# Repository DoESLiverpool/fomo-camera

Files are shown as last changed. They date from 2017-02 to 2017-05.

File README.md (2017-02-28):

# fomo-camera
An internet connected camera for live participatory photography

Fomo camera is an experiment to see what happens when you give a camera to an attendee at an event and then ask them to pass it on to the next person they bump into. The cameras will take images every minute and upload the result to the web.
The hardware will be contained in a large decorated enclosure.

In development for Light Night 17 at Maker Nights @ DoES

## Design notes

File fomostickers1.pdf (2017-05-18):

Fomocam.co.uk
See what we’ve been up to!

Fomocam.co.uk
where have we been?

Fomocam.co.uk
who have we met?
Fomocam.co.uk | Fomocam.co.uk | Fomocam.co.uk

Fomocam.co.uk
See what we’ve been up to!

Fomocam.co.uk
where have we been?

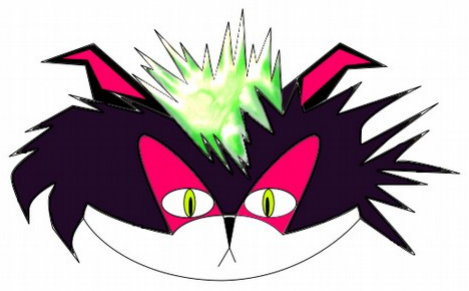
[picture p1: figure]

Fomocam.co.uk
who have we met?
Fomocam.co.uk | Fomocam.co.uk | Fomocam.co.uk

Fomocam.co.uk
See what we’ve been up to!

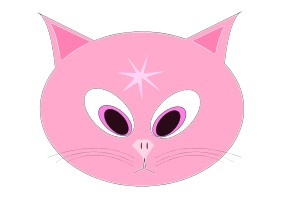
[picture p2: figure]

Fomocam.co.uk
where have we been?

Fomocam.co.uk
who have we met?
Fomocam.co.uk | Fomocam.co.uk | Fomocam.co.uk

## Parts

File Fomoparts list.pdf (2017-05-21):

Fomocam Parts list
Electronics
Raspberry Pi Zero (check it has camera conector so W or V 1.3) Raspbery Pi Camera module V2 or similar e.g. PiNoIR
Pi Zero Camera adaptor cable
NeoPixal strip (WS2812 5050 RGB LED)
8G SD Card
USB Modem Router 3G or 4G
5V powerbank (RS Pro PB-10400 10400mAh Power Bank Portable Charger) USB to MicroUSB B cable x 3
USB conector
3 x short lengths of electronics wire in different colours
Soldering iron & solder

Case
200 x 400mm sheet of 3mm Perspex* 4 x 50mm 2mm threaded bolts
8 x 2M nuts (best to have a few spare!) 2 x 20-25mm 2mm nylon bolts & nuts Hot glue gun & glue

Cover
EVA foam, felt, fur, googly eyes, sparkly things, what ever you want!
See coverings section for advice.
*You can get 3 boxes out of a 400 x 600mm sheet or play around with the layout to use 2 pieces smaller than 200 x 400mm

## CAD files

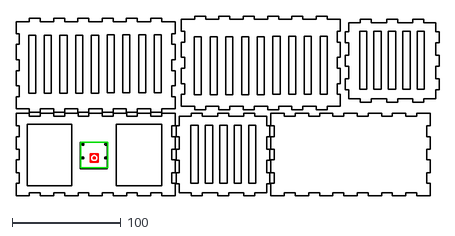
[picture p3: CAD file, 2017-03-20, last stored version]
fomoBox3.dxf
388.2 x 165.2

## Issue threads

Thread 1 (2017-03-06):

Design: Find the right balance of “it’s so cute!” and “it’s obviously a camera”

zarino, 2017-03-06:
I think you need something that:

* Looks like a camera (so it’s really obvious which direction to point it in)
* Looks like a creature with a face (so people look after it)
* Feels comfortable to hold (so people hold it)

Extra points if it lights up, or otherwise attracts attention to itself, so people notice it on the night.

None of these are quite right, but hopefully you can take bits from each (“this one looks a bit like a camera” … “this one is really cute” … “this one is furry”) as inspiration for FOMOcam.

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

/cc @huffeec @frabcus @awesomeliverpool

huffeec, 2017-03-06:
I've just been to chat with the sewing club, they were thinking of something like this. (Sort of similar to the top images..)

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

I really like the idea of building in a screen on the back with instructions too, makes it more interactive.

huffeec, 2017-03-11:
Talked with Dave about this at Maker day. He's looking at designs for the enclosure.
Will post updates here but keep the ideas coming, or speak to Dave..

drfraz, 2017-03-22:
Prototype foam body & perspex hard box for electronics made (see fomotest1.0 a & b in code section).
Initial consumer feedback seems positive for size & ease of throwing. Just need to cover it in fur....

drfraz, 2017-03-24:
Rough sketches for Liv & Mo
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

drfraz, 2017-04-08:
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

first fix

drfraz, 2017-04-08:
If we can't get hold of the sewing club then this might help!
http://laurenvenell.com/epic-how-to-make-a-3-d-plush-pattern-from-a-2-d-drawing/

drfraz, 2017-04-15:
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

drfraz, 2017-04-23:
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

Hope they are cute enough! Weight & fell seemed good with the camera in situ

Closed 2017-04-23.

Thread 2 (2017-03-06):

Investigate phone wifi hotspot as source of Internet connection

zarino, 2017-03-06:
If a mobile data board for the Raspberry Pi is proving expensive, could we instead assign each FOMOcam with a human "minder" who broadcasts a wifi hotspot for the FOMOcam to connect to?

Minders would need a phone, a sim card with sufficient data allowance and tethering enabled, and a spare USB battery pack, probably!!

huffeec, 2017-03-06:
Yes, I think this is the way to go. All we'd really lose, (and maybe not even) would be the accurate location data, which isn't really a problem.

drfraz, 2017-04-08:
Would a 3G modem dongle work OK? like one of these
 http://www.auto-gadget.com/index.php?route=product/product&product_id=58406&currency=GBP
looks a lot cheaper than the specific raspberry pi modems & people seem to be using them OK.
Only downside seems to be the aesthetics but we could remove the cover!

huffeec, 2017-04-23:
Have got and tested an o2 3g usb dongle.
Works on Raspbian and ran for 9 hours on the battery and uploaded images fine.
(I switched it off after nine hours to save data and because that's plenty long enough..)

Closed 2017-04-23.

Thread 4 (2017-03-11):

Check Pyinstagram as a route to upload media to Instagram

huffeec, 2017-03-11:
Look into this as an option to access the Instagram API via Python

https://github.com/eseom/pyinstagram

drfraz, 2017-04-08:
Here is a possible alternative
https://github.com/mgp25/Instagram-API

huffeec, 2017-04-23:
I didn't have much confidence in the Instagram API for this, so I'm currently using ftp to transfer images to a webserver.
[fomocam.co.uk](http://fomocam.co.uk) is running a basic bootstrap page that displays the most recent image and has paginated thumbs for older images. I'll add some social media buttons to encourage sharing and make it easy for us to post highlights to instagram/twitter accounts.

drfraz, 2017-04-23:
Yeah, if we are monitoring the site then we can ping off selected images every so often to the Instagram, twitter accounts, Police etc.

huffeec, 2017-05-05:
This is working now, and no police were needed at Festevol

Closed 2017-05-05.

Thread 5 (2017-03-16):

Name the cameras

huffeec, 2017-03-16:
Currently the cameras don't have particularly friendly names (fomocam1, fomocam2..)
Any suggestions for something a bit more engaging?

So far we've got FomoLiv and FomoMo....

SayBeano, 2017-03-16:
Maybe FomoViv or just Vivian, after Vivian Maier for one?

Her photos were found a few years back [by someone](http://www.johnmaloof.com/) who bought the contents of a storage container, Vivian was traced from a self portrait and later a documentary was made. That's about the most fitting suggestion I have.

The story could be further incorporated into an RFID / NFC / QRC that people inheriting the cameras can scan and be taken off to wikipedia. Mayber.

DoESsean, 2017-03-16:
FomoMoney and FomoProblems.

On Thu, Mar 16, 2017 at 10:05 AM, Mark Sabino <notifications@github.com>
wrote:

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

drfraz, 2017-03-24:
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

Closed 2017-04-23.

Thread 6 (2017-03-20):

Bluecoats meeting

drfraz, 2017-03-20:
Do you think we can meet with Bluecoats on Wednesday?
We need to see where we can project images & find out what they expect from us!
It could be a good place to try & get the 2 cameras to meet up rather than set them off from. Possibly start 1 at the Library & 1 at the Cathedral

huffeec, 2017-03-22:
Rob from Bluecoat is going to be around sometime today to talk about this. Do you want to chat with him? I've copied you into the email so you can pass on your phone number if you do.

drfraz, 2017-03-22:
Hi Chris, I'm at DoES so free to talk, my number is 07887 901668 but I can
pop across to Bluecoats easily
Fraz

On 22 Mar 2017 10:48 am, "huffeec" <notifications@github.com> wrote:

Rob from Bluecoat is going to be around sometime today to talk about this.
Do you want to chat with him? I've copied you into the email so you can
pass on your phone number if you do.

—
You are receiving this because you authored the thread.
Reply to this email directly, view it on GitHub
<https://github.com/DoESLiverpool/fomo-camera/issues/6#issuecomment-288362075>,
or mute the thread
<https://github.com/notifications/unsubscribe-auth/ASdoWVD2C0ogALmKEmOSaW4X1hoPgOUNks5roPyUgaJpZM4MjJBW>
.

huffeec, 2017-03-22:
Cool, Are you ok to chat with them?
Do you want me to pass on your number?

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

huffeec, 2017-03-22:
Chasing my tail a bit this week. But will definitely have a time lapse
ready camera for tomorrow. and I'll get onto the sewing club now.
Hope the exams went well?

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

drfraz, 2017-03-22:
Yes pass it on, just cutting the foam down to size. I will be down tomorrow
night so can catch up

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

huffeec, 2017-03-22:
So in the mean time Rob has called me.

He's offering one of the two TV's in the foyer, connected to a laptop, and
a small table somewhere.
Does that sound ok?

They need to agree it with Marie-Anne though.

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

drfraz, 2017-03-22:
That sounds great, I'll pop in in a bit and send a photo

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

drfraz, 2017-03-22:
I guess it is one of these screens that they mentioned. It would certainly
get a lot of notice. We could use my old laptop as it doesn't matter if it
gets nicked.
Also friendly sized foam.

On 22 Mar 2017 11:30 am, "David Frazer" <lazy.morepork@gmail.com> wrote:

That sounds great, I'll pop in in a bit and send a photo

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

Closed 2017-04-23.

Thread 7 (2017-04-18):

Testing times

drfraz, 2017-04-18:
Good news that we can test Fomocam at the Invisible wind Factory on 30th April!

drfraz, 2017-04-23:
I've opened this as a project. No idea if that's the right thing or not but I like the idea.

huffeec, 2017-04-23:
Why not..

drfraz, 2017-04-29:
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

drfraz, 2017-05-01:
Pretty successful test run here are some of the main issues

Instructions aren't obvious : try parcel tags with them on.
              Web address on one side & instructions on the other?

Kids these days have short attention spans: try photo every 30 seconds.
               Should have enough data & means only 20 seconds when the camera isn't doing something.

IR camera produces some very weird colours: try to make it a feature.
              If we use it in Vivian & say that he sees the world in a different way which can be both disturbing
               &/or beautiful. good for inclusivity of the differently abled, autistic,etc & philosophical; is any   
               world view the right one?

 Very positive feedback & interest from most people with several wanting to buy one

drfraz, 2017-05-01:
Also seems to be plenty of charge left after about 8 hours!

huffeec, 2017-05-05:
I also learned I'm going to need a backup battery for my own phone..

Closed 2017-05-06.

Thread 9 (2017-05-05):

Create instructions label

huffeec, 2017-05-05:
Make a label for the cameras that makes the instructions more obvious.
Include text from back of camera and web address.

Needs to be fairly durable so more than card. What fabrics etch well? Leather?

drfraz, 2017-05-05:
Might be best to do thick card then laminate it once printed. Do we have access to a laminater?
Otherwise I could have a look around Abakhan tomorrow morning.

drfraz, 2017-05-05:
thin plywood could work & I could stick some Danish oil on, for that retro look

drfraz, 2017-05-06:
Files uploaded & wooden tags made for each camera

Closed 2017-05-11.

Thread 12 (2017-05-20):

Step by step construction plan

drfraz, 2017-05-20:
We should try to put together a step by step plan for construction.

1. Parts & Materials
2. Assembling Pi, Camera, Modem, power pack & Neopixals
3. How to cut the box & assemble
4. How to write the code to the SD card
5. Advice on soft coverings etc

Appendix on problems we encountered

Nice to have it ready for Makerfest with lots of pictures.

drfraz, 2017-05-20:
I'll be unavailable from the 26th May till 11th June ;->

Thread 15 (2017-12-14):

Lightnight 2018

drfraz, 2017-12-14:
1. Apply - I'll put in the application this weekend
2. New Features - GPS tracking, Manipulating images
3. 4th Fomocam shaped like Box Brownie?

drfraz, 2017-12-18:
Spoke to Rachel today and they are still waiting to find out what the main Artist requires for her work, which is a dance thing.  They are happy to host us otherwise & will arrange a proper meeting in the new year.

drfraz, 2017-12-28:
Application in!

drfraz, 2018-03-06:
Pi Zero, Cameras & connectors ordered.
Charlotte has asked Sensor city to host.

Things to do:
Write stuff for program (21st March)
Build Box Brownie camera
Sort out GPS
Look at image effects
Plan new website
Build new website

drfraz, 2018-04-14:
Tomorrow;
Check out filters
Build brownie cam
Plan website changes

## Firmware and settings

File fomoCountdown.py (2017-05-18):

import time
import datetime
from picamera import PiCamera
from neopixel import *

# LED strip configuration:
LED_COUNT   = 8      # Number of LED pixels.
LED_PIN     = 18      # GPIO pin connected to the pixels (must support PWM!).
LED_FREQ_HZ = 800000  # LED signal frequency in hertz (usually 800khz)
LED_DMA     = 5       # DMA channel to use for generating signal (try 5)
LED_INVERT  = False   # True to invert the signal (when using NPN transistor level shift)

def countdown(strip, color, wait_ms=500):
	for i in range(strip.numPixels()):
		strip.setPixelColor(i, color)
		strip.show()
		time.sleep(wait_ms/1000.0)

def setAll(strip, color):
	for i in range(strip.numPixels()):
		strip.setPixelColor(i, color)
	strip.show()

def flashAll(strip, color, wait_ms=500):
	for j in range(10):
		if (j % 2 == 0):
			setAll(strip, Color(0, 0, 0))
		else:
			setAll(strip, Color(0, 255, 0))
		strip.show()
		time.sleep(wait_ms/1000.0)



#Create camera object
camera = PiCamera()
camera.resolution = (1024, 768)

# Create NeoPixel object with appropriate configuration.
strip = Adafruit_NeoPixel(LED_COUNT, LED_PIN, LED_FREQ_HZ, LED_DMA, LED_INVERT)
# Intialize the library (must be called once before other functions).
strip.begin()
strip.setBrightness(25)

#Inital countdown warning
countdown(strip, Color(0, 255, 0), 1000)

#warm up camera
camera.start_preview()

#Flash warning that photo is about to be taken
flashAll(strip, Color(0,255,0), 500)

#Change strip color to indicate photo is being taken
setAll(strip, Color(255, 0, 0))

#Take picture
camera.capture('vivian/%s.jpg' % (datetime.datetime.now().strftime("%H:%M:00")))

#Turn off all pixels
setAll(strip, Color(0, 0, 0))

time.sleep(17)

#Inital countdown warning
countdown(strip, Color(0, 255, 0), 1000)

#warm up camera
camera.start_preview()

#Flash warning that photo is about to be taken
flashAll(strip, Color(0,255,0), 500)

#Change strip color to indicate photo is being taken
setAll(strip, Color(255, 0, 0))

#Take picture
camera.capture('vivian/%s.jpg' % (datetime.datetime.now().strftime("%H:%M:30")))
time.sleep(1)

#Turn off all pixels
setAll(strip, Color(0, 0, 0))

camera.close()

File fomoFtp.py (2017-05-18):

import os
import ftplib
import time

#simple ftp uploader for fomocam
#Connects to remote server and uploads all jpgs in piDir
#fomocam.co.uk

#image directory
piDir = "/home/pi/mo"
serverDir = "/public_html/mo/"

#Connect to ftp server
ftp = ftplib.FTP("HOST")
ftp.login("USERNAME", "PASSWORD")
#Change working directory on server
ftp.cwd(serverDir) 

#Loop on all files in piDir
for filename in os.listdir(piDir):
	if filename.endswith('.jpg'):
		curFname = os.path.join(piDir, filename)
		#Upload file to serverDir
		ftp.storbinary('STOR ' + filename, open(curFname, 'rb'))
		#Move local copy of file to /uploaded
		os.rename(curFname, os.path.join(piDir, 'uploaded/' + filename))

time.sleep(30) 

#Loop on all files in piDir
for filename in os.listdir(piDir):
	if filename.endswith('.jpg'):
		curFname = os.path.join(piDir, filename)
		#Upload file to serverDir
		ftp.storbinary('STOR ' + filename, open(curFname, 'rb'))
		#Move local copy of file to /uploaded
		os.rename(curFname, os.path.join(piDir, 'uploaded/' + filename))

#Close ftp connection
ftp.quit()

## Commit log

2017-04-23 Camera control script
2017-04-23 Add files via upload
    Now with slot for camera cable
2017-05-06 Add files via upload
    For thin perspex to glue to felt & help keep camera aligned
2017-05-08 Add files via upload
    Now with Pi board mounts & changed vents
